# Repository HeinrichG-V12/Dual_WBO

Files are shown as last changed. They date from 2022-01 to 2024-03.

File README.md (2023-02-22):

# Dual channel wideband oxygen controller

## Development status

- Hardware: working in progress, check hardware/V0.0.1 for actual status
- Software: not started yet

### Dual WBO controller based on

- Microchip AT90CAN128
- 2x Bosch CJ125 wideband lambda controller
- NXP TJA1050T high speed can transceiver
- Infineon TLE42754D LDO 5v and 450mA
- Analog Devices AD5337 8-bit DAC
- Analog Devices ADR02 5v and 10mA precision reference (0.1%) for TLS115
- Infineon TLS115B0EJ voltage tracker for analog part, provides 5v and 150mA
- ...

### Features

- supports **LSU4.9** probes only
- Automotive grade components
- 2x LSU 4.9 connector (TE 1813139-1)
- 4 layer PCB
- integrated with TunerStudio

### Inputs

- 2x LSU4.9 probes
- CAN HS with up to 1mbit/s
- UART for configuration
- UBat input for activation the controller

### Outputs

- dual analog output, either as 0..5V for Lambda 0.65 to 1.35 **OR** narrow band emulation
- CAN output (AEM X-Series protocol) for both channels and debug messages

### Bosch CJ125 (LQFP32 package) part numbers

|Bosch part number|
|:----------------|
|30615|
|40103|
|30522|

#### A couple of CJ125 ICs

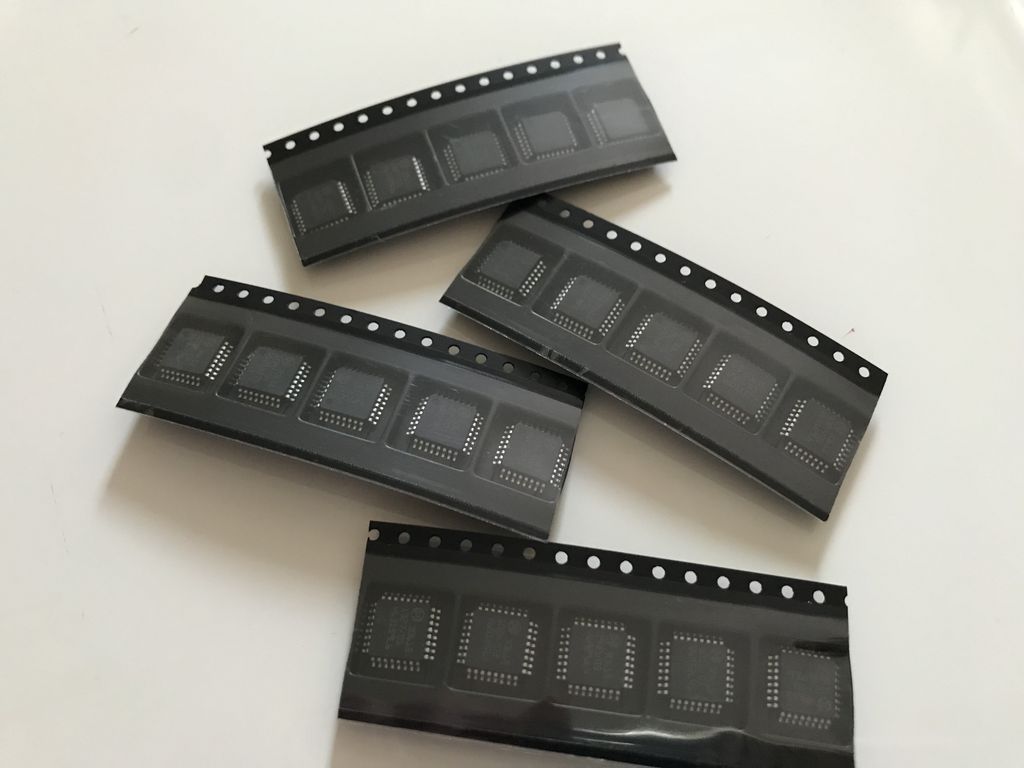
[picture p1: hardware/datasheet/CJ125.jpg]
Bosch CJ125 ICs


### Suitable Bosch lambda probes

Basically, the Bosch probes whose numbers start with **0 258 017** will fit, also Bosch **0 281 004**.  
Bosch numbers beginning with **0 258 007** are *LSU 4.2* probes and will not fit.

|Bosch number  |Length overall|Comment|
|---|---|---|
|0 258 017 012 |1060mm||
|0 258 017 025 |1000mm|Bosch motorsport part|
|0 258 017 029 |620mm|grey, used by BMW after 09/2006 (1178 7539124)|
|0 258 017 038 |340mm|grey, used by BMW (11787537984)|
|0 258 017 092 |950mm|black, used by BMW (1178 7540167)|
|0 258 017 126 |680mm|black, used by BMW after 09/2006 (1178 7561410)|
|0 281 004 028 |540mm||
|0 281 004 150 |1215mm||
|0 281 004 184 |1000mm||
|...|||

### LSU4.9 probe pinout

|Pin#|Color|Description|Symbol|
|----|-----|---|---|
|1|red|Pump current APE|IP|
|2|yellow|Virtual ground IPN|VM|
|3|white|Heater voltage H-|Uh-|
|4|grey|Heater voltaget H+|Uh+|
|5|green|Trim Resistor RT|IA|
|6|black|Nernst voltage UN|RE|

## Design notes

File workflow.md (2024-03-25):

# Workflow for running CJ125

## How CJ125 runs

### Running phases

#### Phase 1, startup

- startup the MCU
- init GPIO, registers, PWM, ADC, DAC, SPI, CAN...

#### Phase 2, calibration

- read diag register of CJ125
- put CJ125 into calibration mode
- read Ua (ADC value for λ=1), store them (Ua_calibration)
- read Ur (ADC value for optimal heater power and heater temperature), store them (Ur_calibration)

#### Phase 3, condensation

- put CJ125 into measurement mode, amplification 17 (VL=1, λ = 0.75...∞)
- drive heater with 1.5V for 5 seconds

#### Phase 4, heat up

- drive heater with 8.5V to 13V (not UBat!), with 0.4V/s

#### Phase 5, running

- PID heater control (read Ur)
- read Ua
- calculate Ip (pump current)

### Ip calculation

#### Ip(A) = (Ua - Ua_calibration) / (amplification * Rshunt)

- Ua: actual Ua value
- Ua_calibration: stored value from calibration step (approx. 1.5V)
- amplification: amplification factor, 8 (rich applications, λ < 1) or 17 (lean applications, λ > 1)
- Rshunt: resistance of shunt resistor between IA and IP for pump current sensing, always 61.9 Ohm for LSU4.2 and LSU4.9

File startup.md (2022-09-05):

# Startup procedure

## Initialization the hardware

- lowlevel init hardware
  - adc
  - spi
  - can network init
  - board init
  - sensor init
  - board read inputs (measure vBat, offset (shunt) and set board status ok/nok)

## Calibration

- bring cj125 into calibration mode
  - wait 500ms
  - check cj125 status
- read calibration values
  - Ua (lambda value)
  - Ur (reference heater value, lower values means hoter heater)

## Running

- bring cj125 into running mode, amplifacation 8
  - wait 500ms
  - check cj125 status
  - set *sensor status* to *evap startup* (pre heating at 1.5v for some time)
- init timer with 1ms

## From now on the while loop is running and scheduler is active

### 10ms task

- if *sensor status* is *running*
  - read Ua, calculate the whole stuff (lambda, O2, ...)
- if *sensor status* is *evap startup*
  - NOP
- always
  - send CAN message with actual values (check DBC file)

### 25ms task

- nothing to do

### 50ms task

- nothing to do

### 100ms task

- if *sensor status* is *running*
  - read Ur
  - adjust pid
- if *sensor status* is *warm up*
  - increase the heater voltage

## Status transitions and actions

- *reset* --> *evap startup*
  - set heater voltage to 1.5v
- *evap startup* --> *warming up*
  - set heater voltage to 8.5v
  - ramp up heater voltage from 8.5v to 13v with maximum ramp up rate of 0.4v/s
- *warming up* --> *running*
  - activate heater pid control
- *running* --> *error*
  - shutdown heater

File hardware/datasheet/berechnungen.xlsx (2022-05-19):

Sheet: ADC
ADC Referenz, V | 5
Auflösung, bit | 10
Volt pro Bit | 0.0048828125
ADC zu Volt | 104 | 0.5078125
Volt zu ADC | 0.51 | 104.448

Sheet: Ip
Ua | 0.51 | 510
Ua_cal | 1.5 | 1500
Diff | -0.99 | -990
amp | 8 | 8
Rshunt | 61.9 | 61.9
Ip | -1.999 | -1.999192246

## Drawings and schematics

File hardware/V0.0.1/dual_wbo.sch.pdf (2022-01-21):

IC3

### XTAL1

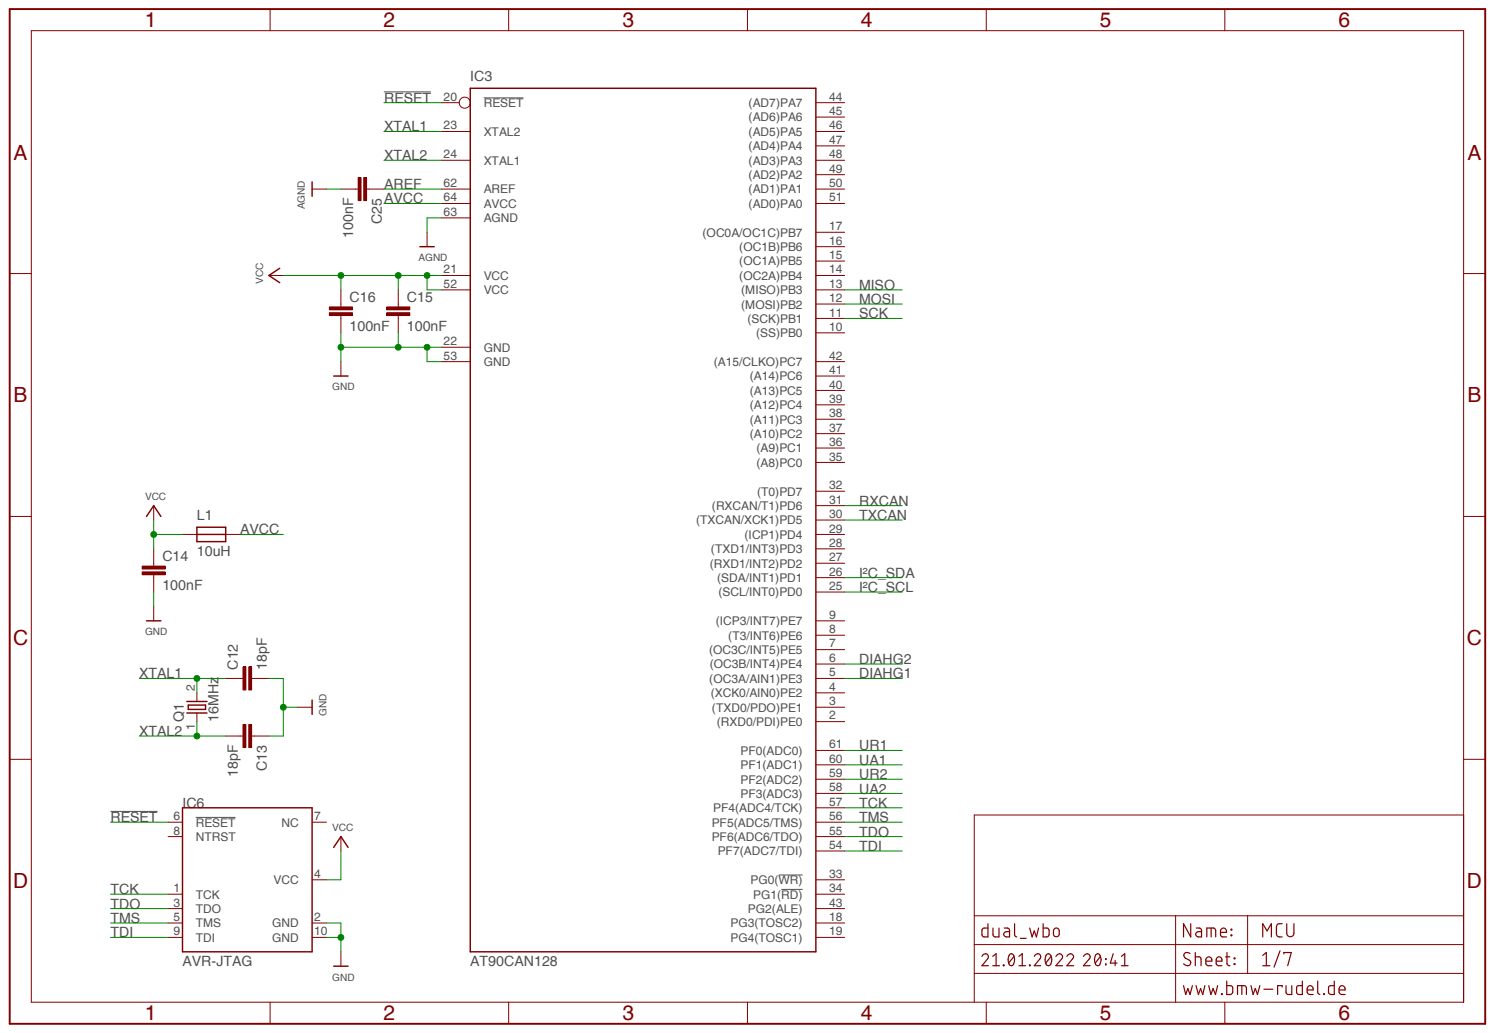
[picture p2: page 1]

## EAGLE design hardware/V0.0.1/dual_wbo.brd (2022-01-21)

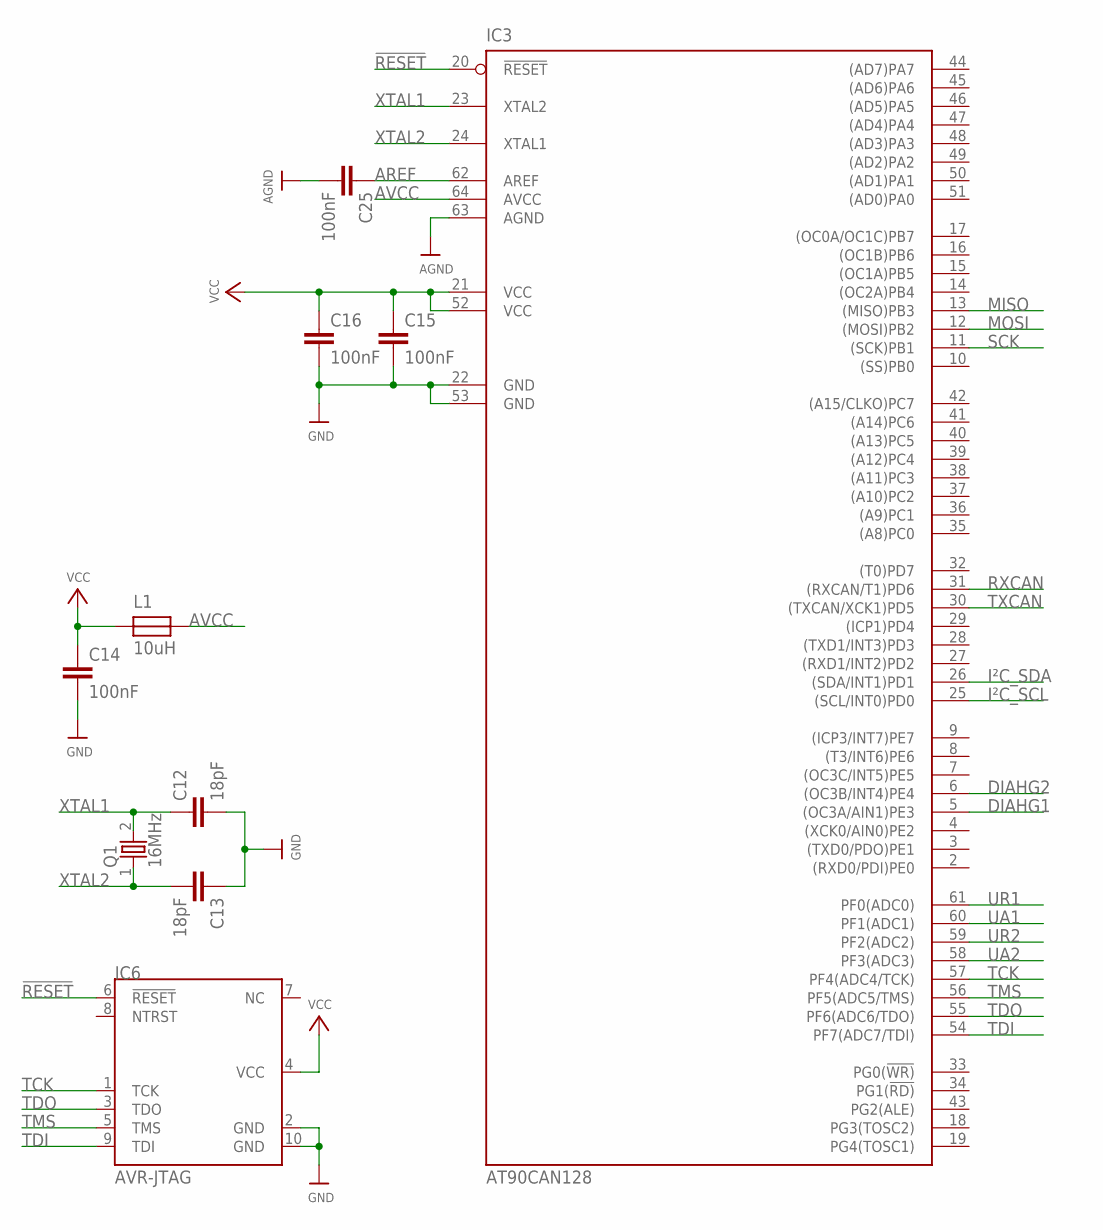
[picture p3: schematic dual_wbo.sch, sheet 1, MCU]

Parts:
C12, C13: 18pF; C0603
C14, C15, C16, C25: 100nF; C0603
IC3: AT90CAN128; TQFP64
IC6: AVR-JTAG; 2X05_1.27MM_SMT
L1: 10uH; R0603
Q1: 16MHz; ABM3

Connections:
!RESET: IC3.20 (!RESET), IC6.6 (!RESET)
AGND: C25.2, IC3.63 (AGND); also elsewhere on the board
AREF: C25.1, IC3.62 (AREF); also elsewhere on the board
AVCC: IC3.64 (AVCC), L1.2
DIAHG1: IC3.5 ((OC3A/AIN1)PE3); also elsewhere on the board
DIAHG2: IC3.6 ((OC3B/INT4)PE4); also elsewhere on the board
GND: C12.2, C13.1, C14.2, C15.2, C16.2, IC3.22 (GND), IC3.53 (GND), IC6.2 (GND), IC6.10 (GND); also elsewhere on the board
I²C_SCL: IC3.25 ((SCL/INT0)PD0); also elsewhere on the board
I²C_SDA: IC3.26 ((SDA/INT1)PD1); also elsewhere on the board
MISO: IC3.13 ((MISO)PB3); also elsewhere on the board
MOSI: IC3.12 ((MOSI)PB2); also elsewhere on the board
RXCAN: IC3.31 ((RXCAN/T1)PD6); also elsewhere on the board
SCK: IC3.11 ((SCK)PB1); also elsewhere on the board
TCK: IC3.57 (PF4(ADC4/TCK)), IC6.1 (TCK)
TDI: IC3.54 (PF7(ADC7/TDI)), IC6.9 (TDI)
TDO: IC3.55 (PF6(ADC6/TDO)), IC6.3 (TDO)
TMS: IC3.56 (PF5(ADC5/TMS)), IC6.5 (TMS)
TXCAN: IC3.30 ((TXCAN/XCK1)PD5); also elsewhere on the board
UA1: IC3.60 (PF1(ADC1)); also elsewhere on the board
UA2: IC3.58 (PF3(ADC3)); also elsewhere on the board
UR1: IC3.61 (PF0(ADC0)); also elsewhere on the board
UR2: IC3.59 (PF2(ADC2)); also elsewhere on the board
VCC: C14.1, C15.1, C16.1, IC3.21 (VCC), IC3.52 (VCC), IC6.4 (VCC), L1.1; also elsewhere on the board
XTAL1: C12.1, IC3.23 (XTAL2), Q1.2
XTAL2: C13.2, IC3.24 (XTAL1), Q1.1

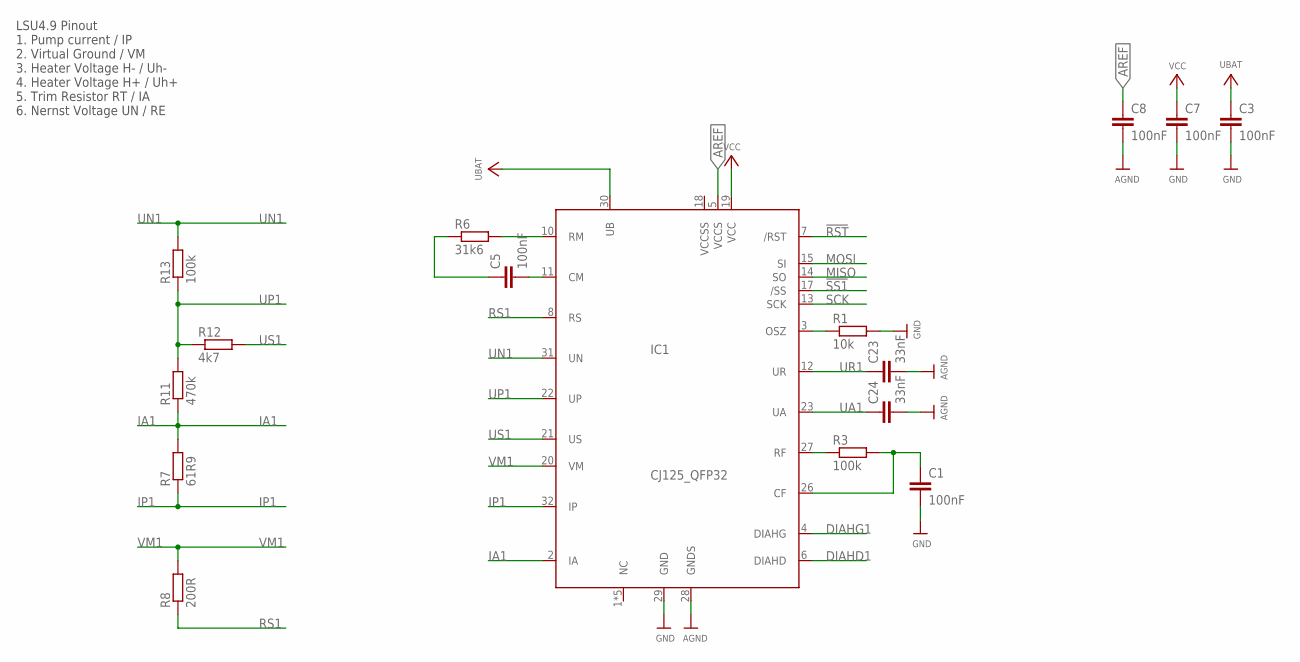
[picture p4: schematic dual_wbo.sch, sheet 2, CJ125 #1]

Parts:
C1, C3, C5, C7, C8: 100nF; C0603
C23, C24: 33nF; C0603
IC1: CJ125_QFP32; TQFP32-08
R1: 10k; R0603
R3, R13: 100k; R0603
R6: 31k6; R0603
R7: 61R9; R0603
R8: 200R; R0603
R11: 470k; R0603
R12: 4k7; R0603

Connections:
!RST: IC1.7 (/RST); also elsewhere on the board
!SS1: IC1.17 (/SS)
+UBAT: C3.1, IC1.30 (UB); also elsewhere on the board
AGND: C8.2, C23.2, C24.2, IC1.28 (GNDS); also elsewhere on the board
AREF: C8.1, IC1.5 (VCCS); also elsewhere on the board
DIAHD1: IC1.6 (DIAHD); also elsewhere on the board
DIAHG1: IC1.4 (DIAHG); also elsewhere on the board
GND: C1.2, C3.2, C7.2, IC1.29 (GND), R1.2; also elsewhere on the board
IA1: IC1.2 (IA), R7.2, R11.1
IP1: IC1.32 (IP), R7.1
MISO: IC1.14 (SO); also elsewhere on the board
MOSI: IC1.15 (SI); also elsewhere on the board
unnamed: IC1.3 (OSZ), R1.1
unnamed: IC1.27 (RF), R3.1
unnamed: C1.1, IC1.26 (CF), R3.2
unnamed: IC1.10 (RM), R6.2
unnamed: C5.1, R6.1
unnamed: C5.2, IC1.11 (CM)
RS1: IC1.8 (RS), R8.1
SCK: IC1.13 (SCK); also elsewhere on the board
UA1: C24.1, IC1.23 (UA); also elsewhere on the board
UN1: IC1.31 (UN), R13.2
UP1: IC1.22 (UP), R11.2, R12.1, R13.1
UR1: C23.1, IC1.12 (UR); also elsewhere on the board
US1: IC1.21 (US), R12.2
VCC: C7.1, IC1.19 (VCC); also elsewhere on the board
VM1: IC1.20 (VM), R8.2

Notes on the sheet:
LSU4.9 Pinout 1. Pump current / IP 2. Virtual Ground / VM 3. Heater Voltage H- / Uh- 4. Heater Voltage H+ / Uh+ 5. Trim Resistor RT / IA 6. Nernst Voltage UN / RE

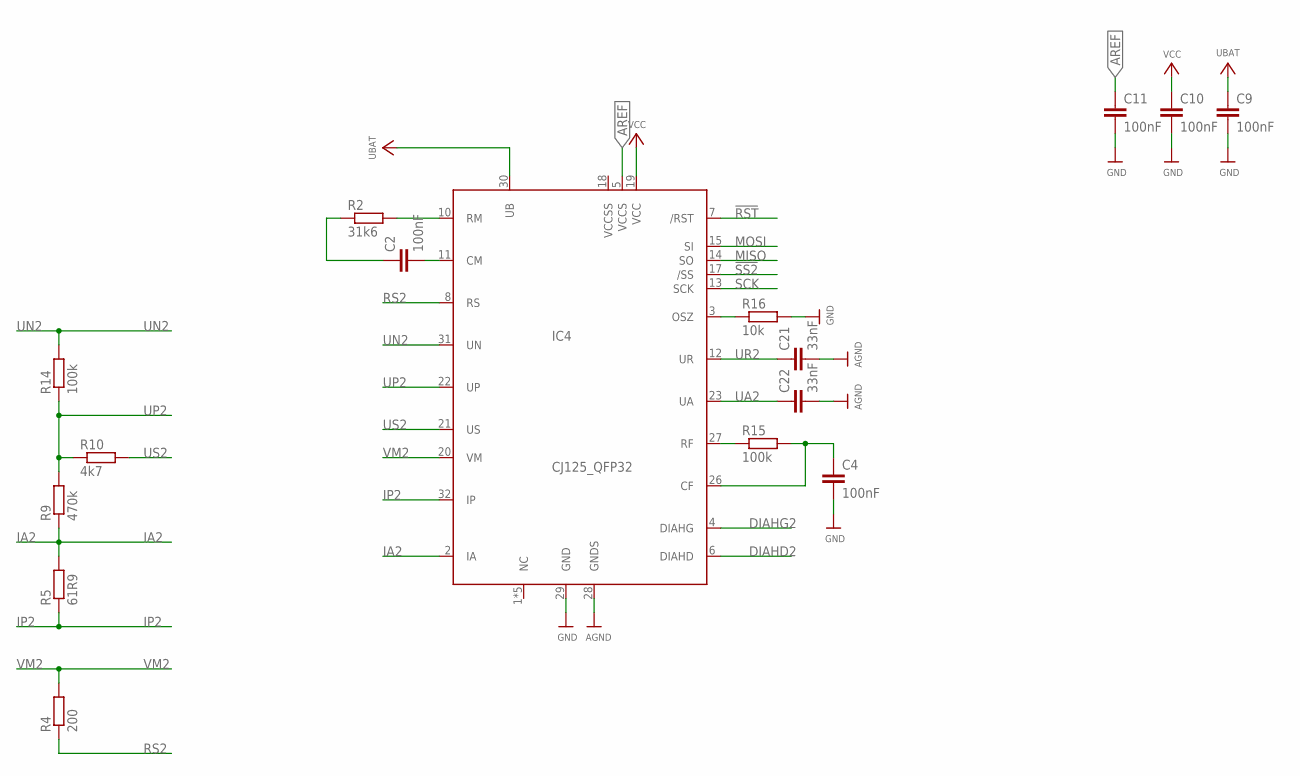
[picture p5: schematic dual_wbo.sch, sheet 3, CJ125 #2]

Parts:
C2, C4, C9, C10, C11: 100nF; C0603
C21, C22: 33nF; C0603
IC4: CJ125_QFP32; TQFP32-08
R2: 31k6; R0603
R4: 200; R0603
R5: 61R9; R0603
R9: 470k; R0603
R10: 4k7; R0603
R14, R15: 100k; R0603
R16: 10k; R0603

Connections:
!RST: IC4.7 (/RST); also elsewhere on the board
!SS2: IC4.17 (/SS)
AGND: C21.2, C22.2, IC4.28 (GNDS); also elsewhere on the board
AREF: C11.1, IC4.5 (VCCS); also elsewhere on the board
DIAHD2: IC4.6 (DIAHD); also elsewhere on the board
DIAHG2: IC4.4 (DIAHG); also elsewhere on the board
GND: C4.2, C9.2, C10.2, C11.2, IC4.29 (GND), R16.2; also elsewhere on the board
IA2: IC4.2 (IA), R5.2, R9.1
IP2: IC4.32 (IP), R5.1
MISO: IC4.14 (SO); also elsewhere on the board
MOSI: IC4.15 (SI); also elsewhere on the board
unnamed: C2.1, R2.1
unnamed: IC4.27 (RF), R15.1
unnamed: C4.1, IC4.26 (CF), R15.2
unnamed: C2.2, IC4.11 (CM)
unnamed: IC4.10 (RM), R2.2
unnamed: IC4.3 (OSZ), R16.1
RS2: IC4.8 (RS), R4.1
SCK: IC4.13 (SCK); also elsewhere on the board
UA2: C22.1, IC4.23 (UA); also elsewhere on the board
UN2: IC4.31 (UN), R14.2
UP2: IC4.22 (UP), R9.2, R10.1, R14.1
UR2: C21.1, IC4.12 (UR); also elsewhere on the board
US2: IC4.21 (US), R10.2
VBAT: C9.1, IC4.30 (UB)
VCC: C10.1, IC4.19 (VCC); also elsewhere on the board
VM2: IC4.20 (VM), R4.2

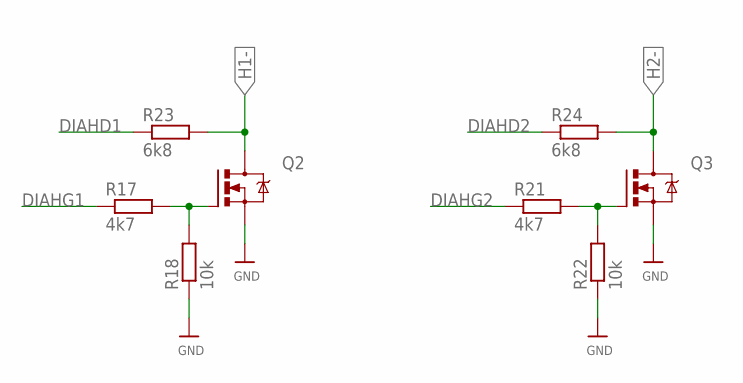
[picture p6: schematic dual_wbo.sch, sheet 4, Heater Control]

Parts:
Q2, Q3: N_MOSFETTO252; TO252
R17, R21: 4k7; R0603
R18, R22: 10k; R0603
R23, R24: 6k8; R0603

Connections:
DIAHD1: R23.1; also elsewhere on the board
DIAHD2: R24.1; also elsewhere on the board
DIAHG1: R17.1; also elsewhere on the board
DIAHG2: R21.1; also elsewhere on the board
GND: Q2.3 (S), Q3.3 (S), R18.1, R22.1; also elsewhere on the board
H1-: Q2.2 (D), R23.2
H2-: Q3.2 (D), R24.2
unnamed: Q2.1 (G), R17.2, R18.2
unnamed: Q3.1 (G), R21.2, R22.2

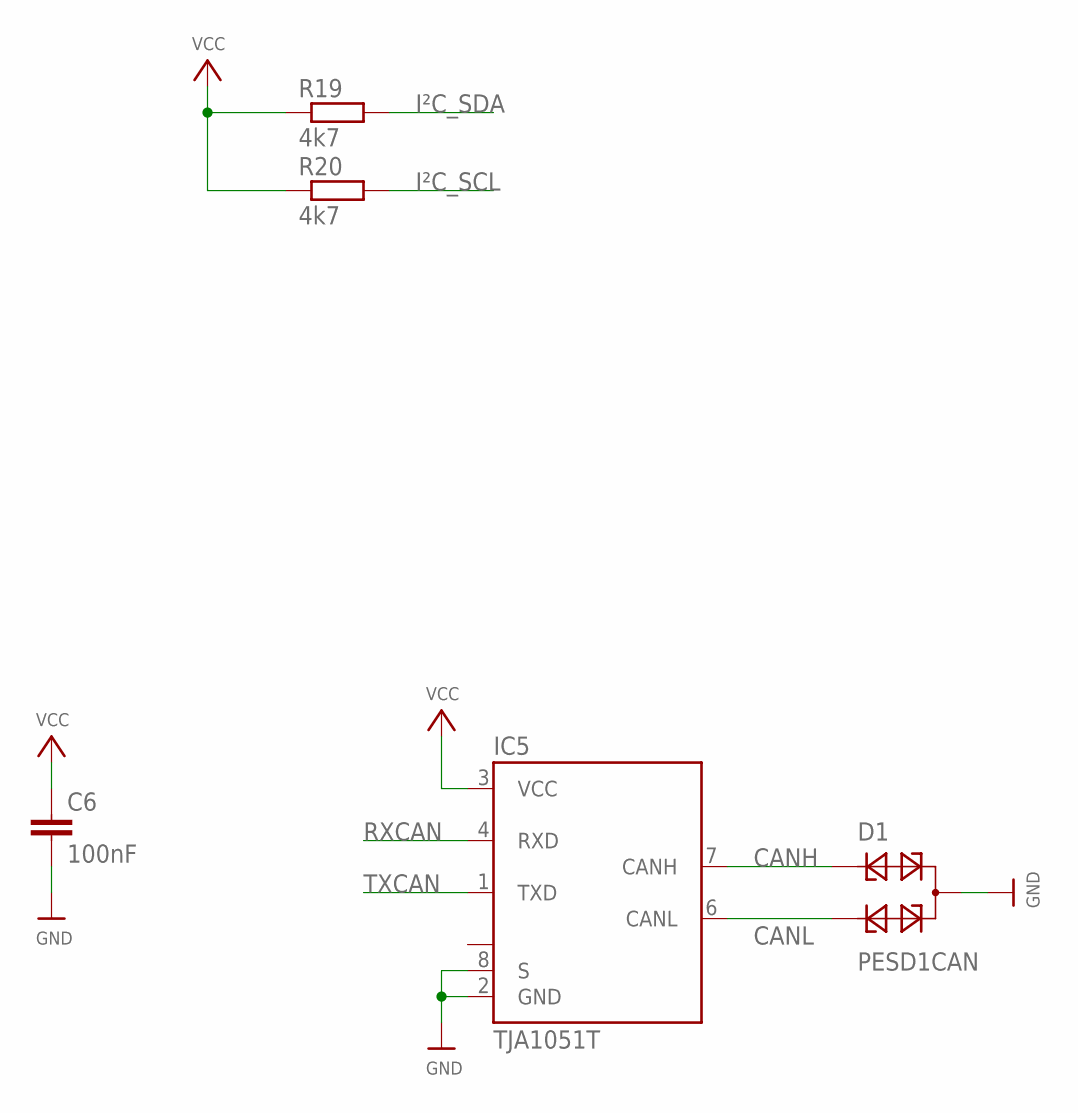
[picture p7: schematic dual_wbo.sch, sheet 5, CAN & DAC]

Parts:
C6: 100nF; C0603
D1: PESD1CAN; SOT23
IC5: TJA1051T; SO8
R19, R20: 4k7; R0603

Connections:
CANH: D1.1, IC5.7 (CANH)
CANL: D1.2, IC5.6 (CANL)
GND: C6.2, D1.3, IC5.2 (GND), IC5.8 (S); also elsewhere on the board
I²C_SCL: R20.2; also elsewhere on the board
I²C_SDA: R19.2; also elsewhere on the board
RXCAN: IC5.4 (RXD); also elsewhere on the board
TXCAN: IC5.1 (TXD); also elsewhere on the board
VCC: C6.1, IC5.3 (VCC), R19.1, R20.1; also elsewhere on the board

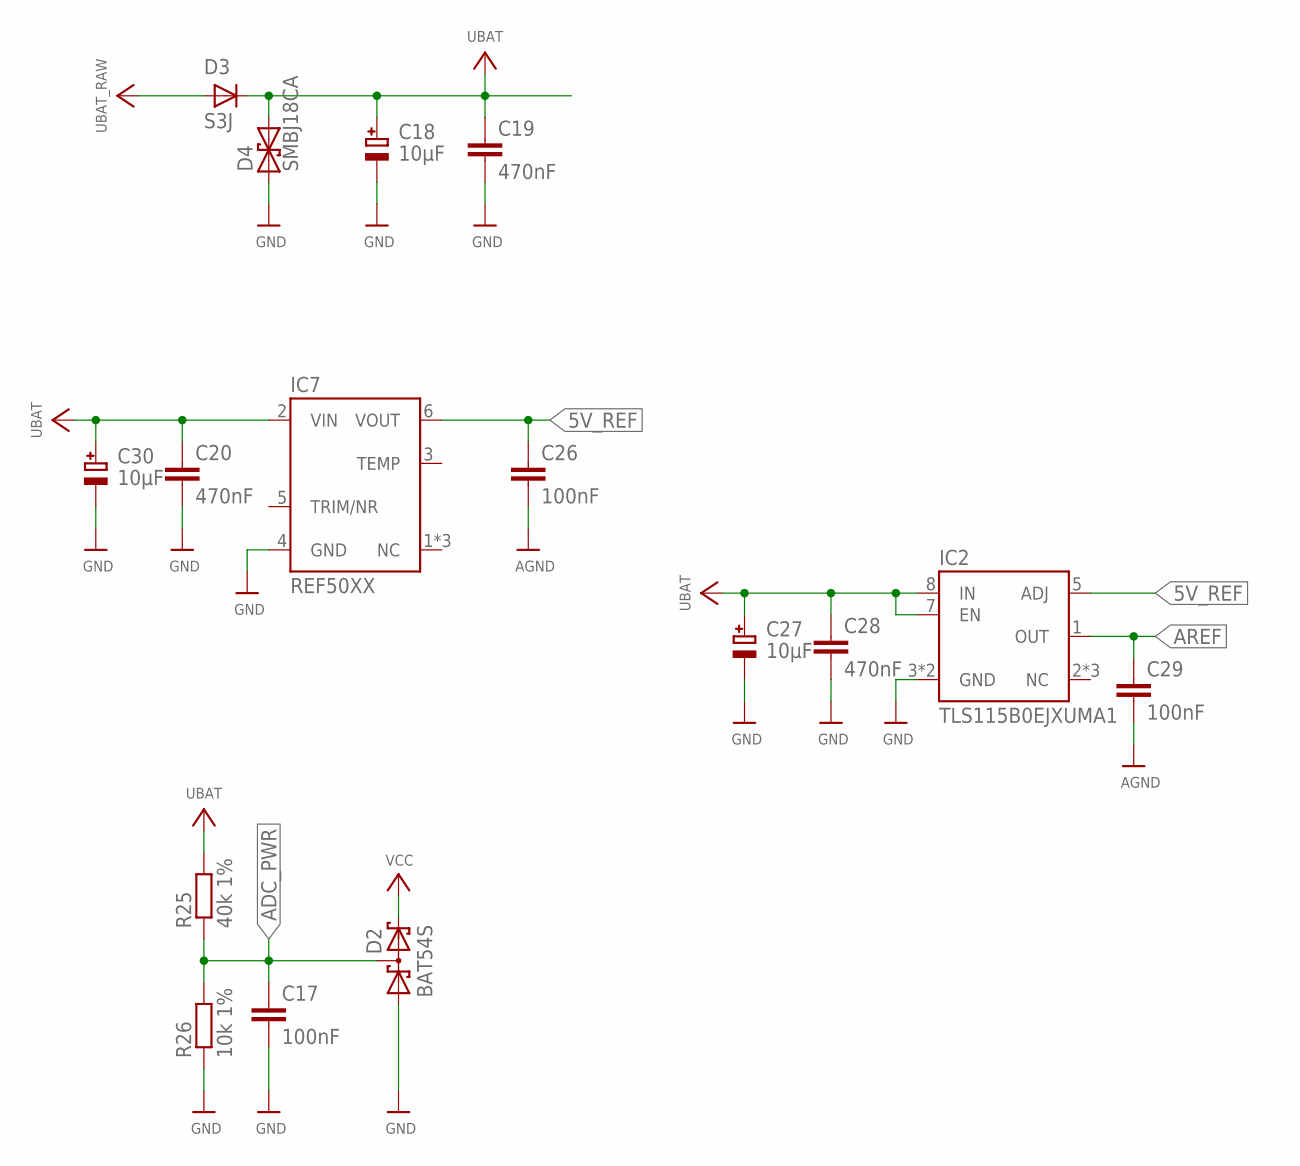
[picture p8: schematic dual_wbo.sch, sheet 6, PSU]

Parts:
C17, C26, C29: 100nF; C0603
C18, C27, C30: 10µF; SMC_C
C19: 470nF; C0805
C20, C28: 470nF; C0603
D2: BAT54S; SOT23
D3: S3J; SMB
D4: SMBJ18CA; DO214AA
IC2: TLS115B0EJXUMA1; SOIC127P600X170-9N
IC7: REF50XX; SOIC127P600X175-8N
R25: 40k 1%; R0603
R26: 10k 1%; R0603

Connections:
5V_REF: C26.1, IC2.5 (ADJ), IC7.6 (VOUT)
+UBAT: C18.+, C19.1, C20.1, C27.+, C28.1, C30.+, D3.A (C), D3.C (A), D4.C (2), IC2.7 (EN), IC2.8 (IN), IC7.2 (VIN), R25.2; also elsewhere on the board
ADC_PWR: C17.1, D2.3 (C1A2), R25.1, R26.2
AGND: C26.2, C29.2; also elsewhere on the board
AREF: C29.1, IC2.1 (OUT); also elsewhere on the board
GND: C17.2, C18.-, C19.2, C20.2, C27.-, C28.2, C30.-, D2.1 (A1), D4.A (1), IC2.3 (GND), IC2.9 (GND), IC7.4 (GND), R26.1; also elsewhere on the board
VCC: D2.2 (C2); also elsewhere on the board

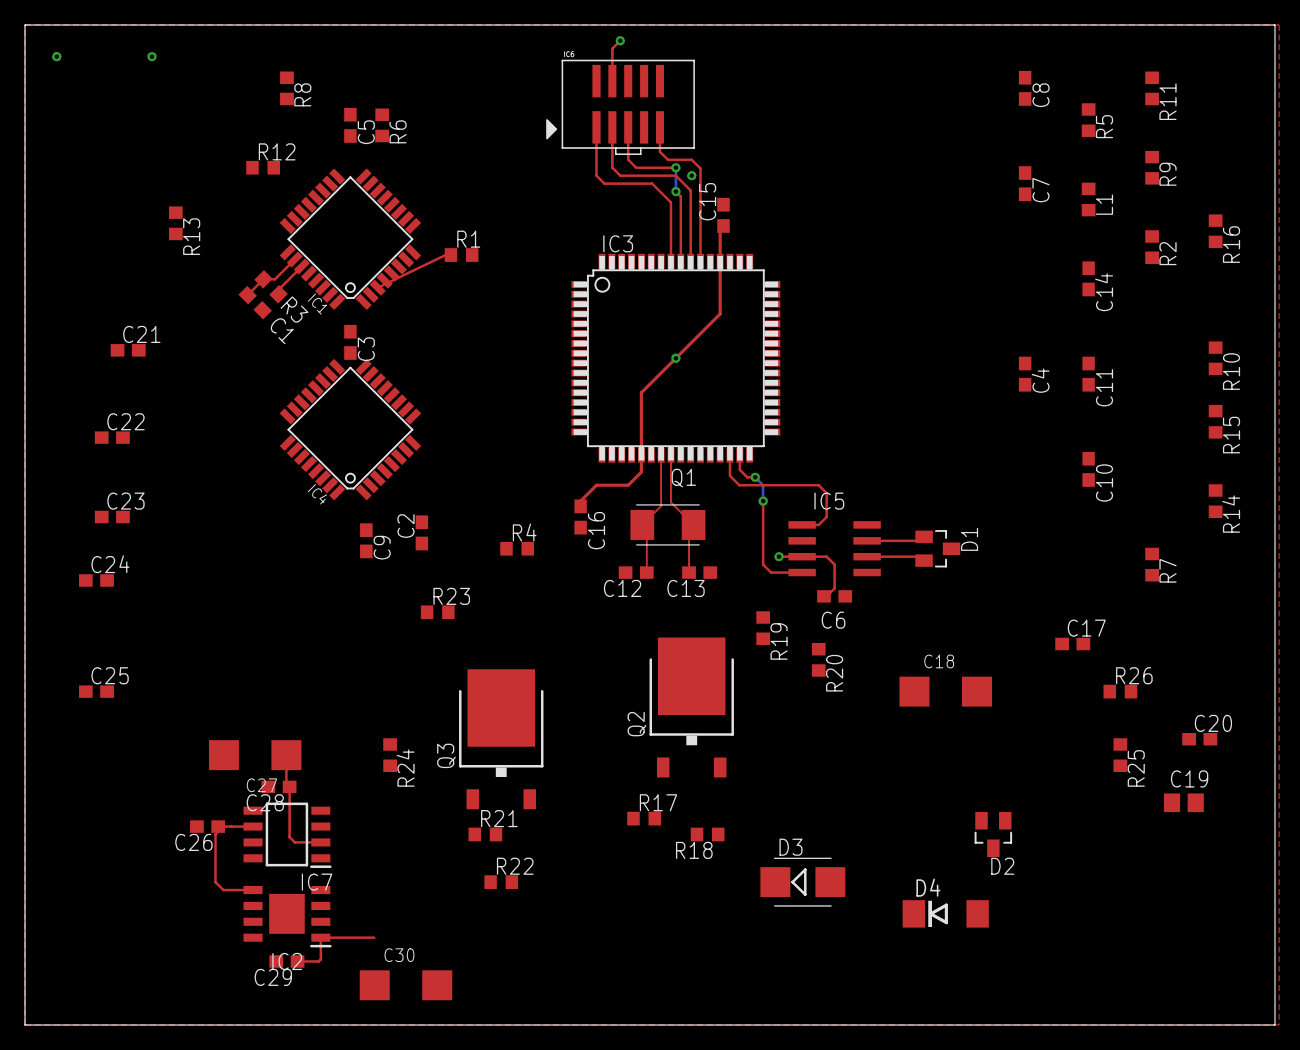
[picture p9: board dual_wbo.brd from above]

Board: 4 copper layers, 100.0 x 80.0 mm, 71 parts (0 on the bottom side), 64 nets.

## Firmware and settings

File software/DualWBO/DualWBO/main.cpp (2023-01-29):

/*
 * DualWBO.cpp
 *
 * Created: 23.01.2023 16:33:34
 * Author : Heinrich
 */ 

#include <avr/io.h>

#include "sensor/sensor.h"
#include "spi/spi.h"
#include "adc/adc.h"

// https://de.wikibooks.org/wiki/C%2B%2B-Programmierung/_Eigene_Datentypen_definieren/_Erstellen_und_Zerst%C3%B6ren
// https://www.oreilly.com/library/view/c-cookbook/0596007612/ch08s10.html
int main(void)
{
	Sensor sensor1 = Sensor();
	Spi* spi = Spi::getInstance();
	spi->spi_readWrite(0xffff);
	Adc* adc = Adc::getInstance();
	adc->readValue(0, 5);
	
    /* Replace with your application code */
    while (1) 
    {
    }
}

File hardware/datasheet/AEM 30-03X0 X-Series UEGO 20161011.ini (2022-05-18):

[View_Vehicles]
HIDDEN=
ORDER=0,1,
DEFINITIONS=
COLUMNWIDTHS=125,150,
[View_Vehicle]
HIDDEN=
ORDER=0,1,
DEFINITIONS=
COLUMNWIDTHS=125,125,
[View_VehicleNetworks]
HIDDEN=3,
ORDER=0,1,2,3,4,5,6,7,8,9,10,
DEFINITIONS=6,7,8,9,10,11,12,
COLUMNWIDTHS=125,125,100,100,150,100,100,50,50,50,50,100,
[View_VehicleNetwork]
HIDDEN=
ORDER=0,1,2,3,4,5,6,
DEFINITIONS=4,5,
COLUMNWIDTHS=125,125,100,125,150,50,100,
[View_VehicleNetworkTxMessages]
HIDDEN=
ORDER=0,1,2,3,4,5,6,7,8,9,10,11,12,
DEFINITIONS=1,2,3,13,
COLUMNWIDTHS=125,125,55,100,50,100,100,100,150,50,100,100,100,
[View_VehicleNetworkSignals]
HIDDEN=
ORDER=0,1,2,3,4,5,6,7,8,9,10,11,12,13,14,15,
DEFINITIONS=
COLUMNWIDTHS=125,125,100,50,100,50,100,100,100,50,50,50,50,100,100,150,
[View_VehicleControlUnit]
HIDDEN=
ORDER=0,1,2,3,4,5,6,
DEFINITIONS=4,5,
COLUMNWIDTHS=125,125,100,125,150,50,100,
[View_VehicleGateways]
HIDDEN=
ORDER=0,1,2,
DEFINITIONS=
COLUMNWIDTHS=125,125,100,
[View_VehicleGatewaySignals]
HIDDEN=
ORDER=0,1,2,3,4,5,6,
DEFINITIONS=
COLUMNWIDTHS=125,125,125,125,125,125,125,
[View_Networks]
HIDDEN=2,
ORDER=0,1,2,3,4,5,6,7,8,9,
DEFINITIONS=6,7,8,9,10,11,12,
COLUMNWIDTHS=125,100,100,150,100,100,50,50,50,50,100,
[View_Network]
HIDDEN=
ORDER=0,1,2,3,4,5,
DEFINITIONS=4,5,
COLUMNWIDTHS=125,125,100,150,50,100,
[View_NetworkTxMessages]
HIDDEN=
ORDER=0,1,2,3,4,5,6,7,8,9,10,11,12,
DEFINITIONS=1,2,3,13,
COLUMNWIDTHS=125,125,55,100,50,100,100,100,150,50,100,100,100,
[View_NetworkTxSignals]
HIDDEN=
ORDER=0,1,2,3,4,5,6,7,8,9,10,11,12,13,14,15,
DEFINITIONS=
COLUMNWIDTHS=125,125,100,50,100,50,100,100,100,50,50,50,50,100,100,150,
[View_NetworkNodeGroup]
HIDDEN=
ORDER=0,1,2,3,4,
DEFINITIONS=4,5,
COLUMNWIDTHS=125,100,150,50,100,
[View_Ecus]
HIDDEN=
ORDER=0,1,
DEFINITIONS=
COLUMNWIDTHS=125,150,
[View_Ecu]
HIDDEN=
ORDER=0,1,2,3,4,5,
DEFINITIONS=4,5,
COLUMNWIDTHS=125,125,100,150,50,100,
[View_EnvVars]
HIDDEN=
ORDER=0,1,2,3,4,5,6,7,8,9,
DEFINITIONS=
COLUMNWIDTHS=125,100,100,50,50,50,50,100,100,150,
[View_EnvVar]
HIDDEN=
ORDER=0,1,2,3,4,5,6,7,8,9,10,
DEFINITIONS=
COLUMNWIDTHS=125,125,100,100,50,50,50,50,100,100,150,
[View_NodeGroups]
HIDDEN=
ORDER=0,1,
DEFINITIONS=
COLUMNWIDTHS=125,150,
[View_NodeGroup]
HIDDEN=
ORDER=0,1,2,3,
DEFINITIONS=
COLUMNWIDTHS=125,125,55,150,
[View_Nodes]
HIDDEN=
ORDER=0,1,2,3,4,
DEFINITIONS=4,5,
COLUMNWIDTHS=125,100,150,87,100,
[View_Node]
HIDDEN=
ORDER=0,1,2,3,4,5,6,7,8,9,10,11,12,13,14,
DEFINITIONS=
COLUMNWIDTHS=125,125,100,50,50,100,100,100,50,50,50,50,100,100,150,
[View_NodeTxMessages]
HIDDEN=
ORDER=0,1,2,3,4,5,6,7,8,9,10,11,
DEFINITIONS=1,2,3,13,
COLUMNWIDTHS=125,125,55,100,50,100,100,150,50,100,100,100,
[View_NodeTxMsg]
HIDDEN=
ORDER=0,1,2,3,4,5,6,7,8,9,10,11,12,13,14,
DEFINITIONS=
COLUMNWIDTHS=125,125,100,50,50,100,100,100,50,50,50,50,100,100,150,
[View_NodeTxSignals]
HIDDEN=
ORDER=0,1,2,3,4,5,6,7,8,9,10,11,12,13,14,
DEFINITIONS=
COLUMNWIDTHS=125,125,100,50,50,100,100,100,50,50,50,50,100,100,150,
[View_NodeRxSignals]
HIDDEN=
ORDER=0,1,2,3,4,5,6,7,8,9,10,11,12,13,14,
DEFINITIONS=
COLUMNWIDTHS=125,125,100,50,50,100,100,100,50,50,50,50,100,100,150,
[View_NodeTxSigs]
HIDDEN=
ORDER=0,1,2,3,4,5,6,7,8,9,10,11,12,
DEFINITIONS=
COLUMNWIDTHS=125,125,50,100,100,100,50,50,50,50,100,100,150,
[View_NodeRxSigs]
HIDDEN=
ORDER=0,1,2,3,4,5,6,7,8,9,10,11,12,
DEFINITIONS=
COLUMNWIDTHS=125,125,50,100,100,100,50,50,50,50,100,100,150,
[View_Messages]
HIDDEN=
ORDER=0,1,2,3,4,5,6,7,8,9,10,11,
DEFINITIONS=1,2,3,13,
COLUMNWIDTHS=125,55,100,50,100,100,100,150,50,100,100,100,
[View_Message]
HIDDEN=
ORDER=0,1,2,3,4,5,6,7,8,9,10,11,12,13,14,
DEFINITIONS=
COLUMNWIDTHS=240,125,100,50,50,100,100,100,50,50,50,50,100,206,150,
[View_Signals]
HIDDEN=
ORDER=0,1,2,3,4,5,6,7,8,9,10,11,
DEFINITIONS=
COLUMNWIDTHS=125,50,100,100,100,50,50,50,50,100,100,150,
[View_ValueTables]
HIDDEN=
ORDER=0,1,
DEFINITIONS=
COLUMNWIDTHS=125,150,
[View_AttrDefs]
HIDDEN=6,
ORDER=0,1,2,3,4,5,
DEFINITIONS=
COLUMNWIDTHS=125,100,100,50,50,100,150,

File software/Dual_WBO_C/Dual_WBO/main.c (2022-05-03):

/*
 * Dual_WBO.c
 *
 * Created: 12.12.2021 20:00:16
 * Author : Heinrich
 */ 

#include <avr/io.h>

#include "can/can_lib.h"

int main(void)
{
	uint8_t data[] = "Hallo";
	can_init(0);
	
	st_cmd_t canMsg;
	
	canMsg.id.ext = 0x180;
	canMsg.pt_data = &data[0];
	canMsg.dlc = 5;
	canMsg.cmd = CMD_TX_DATA;
	
	while(can_cmd(&canMsg) != CAN_CMD_ACCEPTED); // wait for MOb to configure
	
	while(can_get_status(&canMsg) == CAN_STATUS_NOT_COMPLETED); // wait for a transmit request to come in, and send a response
	
	
    /* Replace with your application code */
    while (1) 
    {
    }
}

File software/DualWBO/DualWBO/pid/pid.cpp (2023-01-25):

/*
 * pid.cpp
 *
 * Created: 23.01.2023 16:41:18
 *  Author: Heinrich
 */ 

#include "pid.h"

PID::PID(float pGain, float iGain, float dGain, int16_t pwmMin, int16_t pwmMax)
{
	this->pGain = pGain;
	this->iGain = iGain;
	this->dGain = dGain;
	this->pwmMin = pwmMin;
	this->pwmMax = pwmMax;
}

uint16_t PID::calculate(uint16_t referenceValue, uint16_t measuredValue, bool inverted)
{
	float pTerm = 0, iTerm = 0, dTerm = 0;
	// calculation error:
	int16_t error = (int16_t) referenceValue - (int16_t) measuredValue;
	int16_t position = (int16_t) measuredValue;
	
	// calculate p-term;
	if (inverted)
	{
		pTerm = -this->pGain * error;
		} else {
		pTerm = this->pGain * error;
	}
	
	//Calculate the integral state
	this->iState += error;
	
	// check limits of iState
	if (this->iState > this->iMax) this->iState = this->iMax;
	if (this->iState < this->iMin) this->iState = this->iMin;
	
	//Calculate the integral term.
	if (inverted)
	{
		iTerm = -this->iGain * this->iState;
		} else {
		iTerm = this->iGain * this->iState;
	}
	
	//Calculate the derivative term.
	if (inverted)
	{
		dTerm = -this->dGain * (this->dState - position);
		} else {
		dTerm = this->dGain * (this->dState - position);
	}
	this->dState = position;
	
	//Calculate regulation (PI).
	int16_t RegulationOutput = pTerm + iTerm + dTerm;
	
	// check limits of pwm here....
	
	if (RegulationOutput > this->pwmMax)
	{
		RegulationOutput = this->pwmMax;
	}
	
	if (RegulationOutput < this->pwmMin)
	{
		RegulationOutput = this->pwmMin;
	}
	
	return  (uint16_t) RegulationOutput;
}

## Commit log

2021-12-06 bosch probes added
2021-12-11 -> some data sheets added -> added eagle files in hardware/V0.0.1 -> readme.md modified
    [dual_wbo.brd, dual_wbo.sch]
2021-12-12 -> dac name corrected -> dac datasheet added
    [dual_wbo.brd, dual_wbo.sch]
2021-12-14 Schematic updated
2022-01-21 some changes
    [dual_wbo.brd, dual_wbo.sch]
2022-02-16 lsu 4.9 connector erder number added
2022-05-03 pwm basics
2022-05-03 pid basics
2022-05-03 uart buffer basics
2022-05-18 ini file corrected and extended, added curve editor
    [AEM 30-03X0 X-Series UEGO 20161011.ini, main.c, uart.c]
2022-05-19 pump current calculation added, lambda calculation added, some change
    [berechnungen.xlsx]
2022-09-09 lsu probes description

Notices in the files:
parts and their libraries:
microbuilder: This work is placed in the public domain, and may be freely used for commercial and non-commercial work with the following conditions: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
